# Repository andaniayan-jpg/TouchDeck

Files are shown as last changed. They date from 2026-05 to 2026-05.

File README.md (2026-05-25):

# TouchDeck

A macropad with touch sensor
TouchDeck product

Touchdeck is a macropad with touch sensitive display, it has no keys. 

## Table of Contents

WHAT IS TOUCHDECK
WHAT MAKES IT UNIQUE
FEATURES
HOW TO USE IT
BILL OF MATERIALS
SCHEMATIC OVERVIEW
PCB details
3D design 
Assembly Guide
Firmware

---

## What is TouchDeck?

TouchDeck is a device made with ESP32 as the MCU, it acts a touch pad making it both a macropad and a scribble pad. It has 2 modes.

**1.  Macropad Mode**
The screen acts like a touchpad, which digital keys visible on the screen, it enables the device to act as a Touch Screen MacroPad.

**2. Scribble Pad Mode**
When switched to Scribble pad mode, it shows a plain white canvas that can be used to take notes, doodle and etc. NOTHING IS SAVED PERMANENTLY, ONCE EXITING THIS MODE, REMOVES ALL THE WORK. 
---

## What Makes It Unique

It is unique because it doesnt use any buttons or keys like ordinary macropad, it has touch screen. It is unique because it acts as both macropad and scribble pad.
It has a customised PCB, LED, buzzer and  etc.
---

## Main Features

- ESP32-S3 based custom PCB
- 3.5 inch SPI TFT touchscreen display
- XPT2046 touch controller
- USB-C power and data
- On-screen macro buttons
- Temporary scribble/doodle mode
- Back and clear controls
- USB HID keyboard shortcut output
- WS2812B RGB status LED
- Buzzer feedback

PCB top view
PCB bottom view

---

## How to Use It

### 1. Power the Device

Connect the device with the laptop or PC. Turn on with power switch, RGB LED turns on and shows the status.

### 2. Select the mode, Macropad or scribble. 

When powered on, the screen shows two main options:

- **MacroPad Mode**
- **ScribblePad Mode**

Tap the mode you want to use.

### 3. MacroPad Mode

The touchscreen shows several shortcut buttons. When a button is touched, the ESP32-S3 sends a keyboard shortcut to the connected laptop via USB HID.

You can add, remove, increase and reduce the sizes of buttons according to your choice by changing the firmware, as it is a custom PCB!!!

### 4. ScribblePad Mode

The screen becomes a temporary drawing area. You can write with your finger or a capacitive stylus, doodle quick ideas, sketch small layouts, or scribble notes while thinking.

The drawing is **not saved** — it is purely temporary.

- **Clear** — removes the drawing from the screen
- **Back** — returns to the home screen and clears the canvas

UI overview

---

## Bill of Materials (BOM)

visit "" for BOM. 

> 
## Component connections
   for component connections, refer to the schematic image or go through the schematic source file to view exact connections. 

## Assembly Guide
   All the components used are present in the folder `cad_assembly` in STEP/STP format, for 3D model, Enclousre, and 3D parts  overview, go through that folder.

### Tools needed
-Soldering iron and flux
-Tweezers
-USB-C data cable

---
### Step 1 — Solder the Small Components

Let's start by soldering the tiny parts. First, apply some flux to the pads where the resistors and capacitors will go. Carefully position each component in place and solder them down. Since resistors and capacitors are the smallest parts, it's easier to tackle these first.

### Step 2 — Solder the USB-C Connector 

Next up is the USB-C connector. Begin by putting a little solder on the ground pads in the center of the PCB. Align the USB-C connector so all the pins match up with the pads. Tack down one corner to hold it in place, then double-check everything’s aligned before soldering the rest. Finally, solder the 5V and ground shield tabs — these will need a bit more heat to get a good connection.

### Step 3 — Solder the Voltage Regulator and ESD IC

Time to solder the voltage regulator and ESD IC. Start with the AP2112K (U2) in its SOT-23-5 package. Just make sure to pay attention to the orientation according to the silkscreen. After that, move on to the USBLC6-2SC6 (U3) in its SOT-23-6 package, keeping an eye on the pin 1 indicator.

### Step 4 — Solder the Transistor and Buzzer

For the next step, solder the transistor (Q1), which is the 2N3904 in the SOT-23 footprint. Then, insert the passive buzzer (LS1) into the through-hole, making sure the positive marking aligns with the pad label. Solder it from the bottom.

### Step 5 — Solder the WS2812B LED (U4)

Next, let’s work on the WS2812B LED, which has an integrated controller. First, apply a bit of flux to all four pads. Solder one of the corner pads first, then work on the others. Just a tip: try not to apply heat for too long on each pad.

### Step 6 — Solder the Push Buttons

Moving on, place the push buttons (SW1 for Boot and SW2 for Reset) into their through-holes. Insert them from the top and then solder their four legs from the bottom.

### Step 7 — Solder the ESP32-S3-WROOM-1 Module

This is one of the most important parts of the project. Start by applying flux on all the pads on three sides of the module footprint. Carefully position the module, ensuring the edges align with the PCB pads. Tack down two corner pads to secure it, then solder each pad using a drag-soldering method or solder wick. Make sure to check under a magnifying glass to spot any solder bridges.

Remember: **Do not solder the antenna area.** The module has a PCB antenna, so keep that section clear.

### Step 8 — Solder the Display Connector (J2)

Now, insert the 1×14 female header into J2. If you’re not using a header, you can solder wires directly instead. Solder all 14 pins from the bottom.

### Step 9 — Power-On Test (Before Display)

Before connecting the display, let's check if the power is working. Connect a USB-C cable from the board to your computer. Use a multimeter to measure the voltage between the 3.3V test point and ground. You should see a reading between **3.28–3.35V**. If it’s 0V or over 3.4V, disconnect immediately and check the solder joints on U2 and C1/C2.

### Step 10 — Attach the Display Module

Now it’s time to add the 3.5" ILI9488 display module into J2. Be careful to check the pin 1 orientation — there’s a marking on the silkscreen to help you out. If you’re doing a permanent build, you might want to use a little hot glue or double-sided foam tape to hold the display flat against the PCB.

### Step 11 — Mount Everything in the Enclosure

Finally, position the PCB in the bottom of the enclosure, making sure the mounting holes line up with the standoff posts. Insert the M2.5 × 6mm standoffs from below through the PCB holes. Then, place the enclosure top frame over the display and secure it with M2.5 × 4mm screws on both the top and bottom. 

And that’s it! At this point, you should have everything nicely assembled and ready to go.

---

---

Hardware design files are released under CERN Open Hardware Licence v2 (CERN-OHL-S).
Firmware source code is released under MIT License.
See `LICENSE` for full terms.

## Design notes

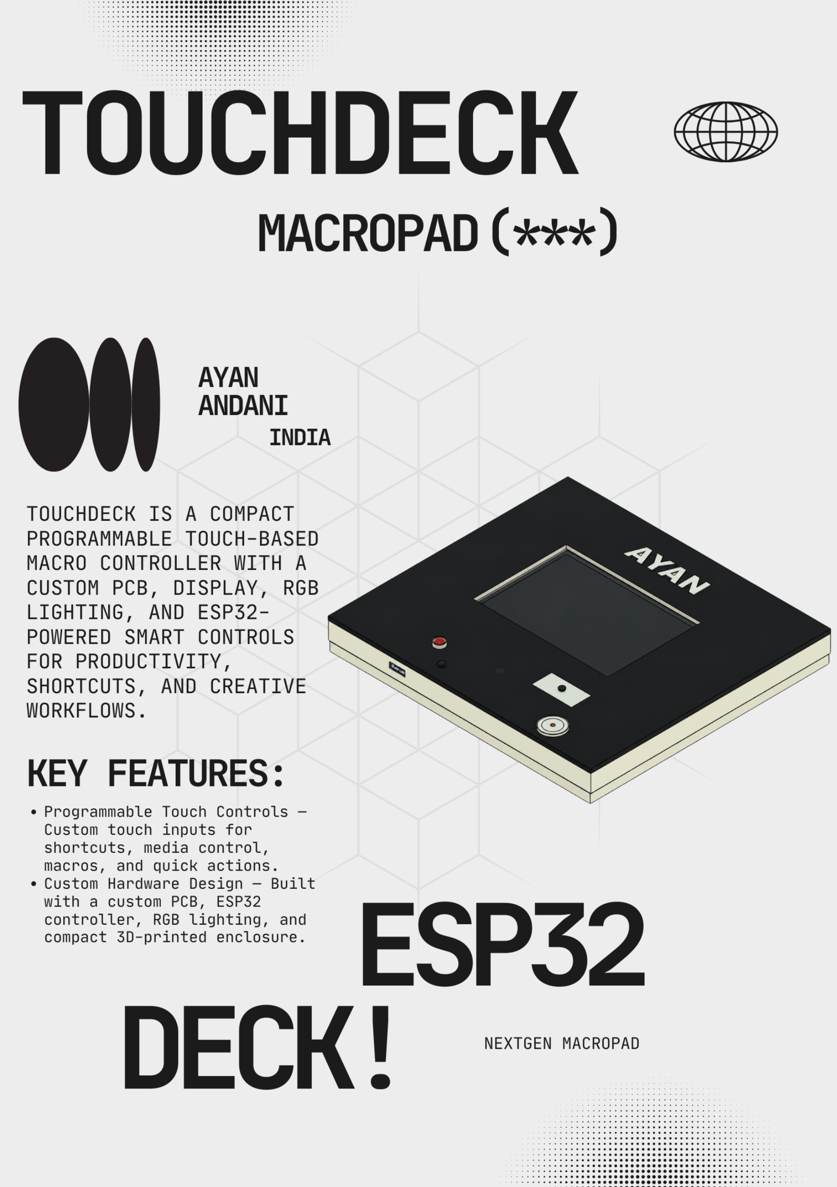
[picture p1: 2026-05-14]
Touch_Deck_zin_page.png

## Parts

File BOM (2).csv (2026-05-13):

Reference | Qty | Component | Value/Part | Footprint | Source | Link | Notes
U1 | 1 | MCU Module | ESP32-S3-WROOM-1-N8R8 | ESP32-S3-WROOM-1 | Espressif / Robu | https://www.espressif.com/en/module/esp32-s3-wroom-1-en | Main ESP32-S3 module with native USB HID capability for macropad output
Q1 | 1 | NPN Transistor | 2N3904 | TO-92_Inline | LCSC | https://www.lcsc.com/product-detail/C118538.html | Buzzer driver transistor
D1 | 1 | LED | SFH4546 5mm IR LED | LED_D5.0mm | DigiKey / ams OSRAM | https://www.digikey.in/en/products/detail/ams-osram-usa-inc/SFH-4546/2205956 | Indicator/LED footprint from PCB export; verify this is the intended LED before ordering
R6,R5 | 2 | Resistor | 10k? 0603 | R_0603_1608Metric | LCSC | https://www.lcsc.com/product-detail/C269701.html | EN/BOOT pull-up resistors
R8,R7 | 2 | Resistor | 1k? 0603 | R_0603_1608Metric | LCSC | https://www.lcsc.com/product-detail/C22548.html | Buzzer transistor base resistor and power LED/current-limit resistor
SW2,SW1 | 2 | Push Button | 6x6mm tactile push button | SW_PUSH_6mm | LCSC | https://www.lcsc.com/product-detail/C393938.html | BOOT and RESET buttons
U3 | 1 | Voltage Regulator | AP2112K-3.3 | SOT-23-5 | LCSC | https://www.lcsc.com/product-detail/C23380830.html | 3.3V LDO regulator from USB 5V
R9 | 1 | Resistor | 330 0603 | R_0603_1608Metric | LCSC | https://www.lcsc.com/product-detail/C23138.html | Series resistor for WS2812B data line
BZ1 | 1 | Buzzer | 12mm through-hole active buzzer | Buzzer_12x9.5RM7.6 | LCSC | https://www.lcsc.com/product-detail/C360615.html | Touch feedback buzzer; footprint Buzzer_12x9.5RM7.6
C1,C2 | 2 | Capacitor | 10µF 0805 ceramic capacitor | C_0805_2012Metric | LCSC | https://www.lcsc.com/product-detail/C89827.html | AP2112K regulator input/output capacitors
R1,R2 | 2 | Resistor | 5.1k? | R_0603_1608Metric | LCSC | https://www.lcsc.com/product-detail/C105580.html | USB-C CC1/CC2 pull-down resistors
U4 | 1 | USB ESD Protection | USBLC6-2SC6 | SOT-23-6 | LCSC / STMicroelectronics | https://www.lcsc.com/product-detail/C2827654.html | ESD protection for USB D+ and D- lines
D2 | 1 | Addressable RGB LED | WS2812B-B/W SMD5050-4P | LED_WS2812B_PLCC4_5.0x5.0mm_P3.2mm | LCSC | https://www.lcsc.com/product-detail/C114586.html | Mode/status RGB LED
J2 | 1 | Display Connector | 1x14 2.54mm vertical header | PinHeader_1x14_P2.54mm_Vertical | KiCad standard footprint / generic electronics supplier | https://www.lcsc.com/category/568.html | Connector footprint for external 3.5 inch SPI TFT touch display module
J1 | 1 | USB-C Receptacle | HCTL HC-TYPE-C-16P-01A | USB_C_Receptacle_HCTL_HC-TYPE-C-16P-01A | LCSC / JLCPCB | https://www.lcsc.com/product-detail/C2894897.html | USB-C power/programming/HID connection
C7 | 1 | Capacitor | 1µF 0805 ceramic capacitor | C_0805_2012Metric | LCSC | https://www.lcsc.com/product-detail/C91186.html | EN/reset stability capacitor
PCB1 | 1 | Custom PCB | TouchDeck / ScribbleDeck PCB | Gerber-manufactured PCB | JLCPCB / PCBWay | https://github.com/andaniayan-jpg/TouchDeck/blob/ea78aa653e28143bab8d7112f781ad645142ba18/pcb_source_files/TOUCHdeck%20GERBERS.zip | Main printed circuit board manufactured from Gerber files; PCB itself is included as a BOM item
DISP1 | 1 | Touch Display Module | 3.5 inch SPI TFT LCD ILI9488 + XPT2046 touch module | External module connected through J2 1x14 header | Robokits / electronics supplier | https://robokits.co.in/displays/lcd-display/spi-tft-3.5-lcd-touch-module-ili9488-driver-480x320 | Main touchscreen used for macro buttons and temporary scribble pad
CASE1 | 1 | Enclosure | Custom 3D printed TouchDeck enclosure | 3D printed part | Self-printed / 3D printing service | CAD/TouchDeck_enclosure.step | Outer case for touchscreen device
CABLE1 | 1 | USB-C Cable | USB-C data/power cable | External cable | Amazon / electronics supplier | https://www.amazon.in/Type-C-Data-Cable/s?k=Type-C+Data+Cable | Used for power, programming, and USB HID connection to laptop
MECH1 | 1 | Mounting Hardware | M2.5 hex screws | Mechanical hardware | Amazon / hardware supplier | https://www.amazon.in/binifiMux-190pcs-Socket-Assortment-Stainless/dp/B07PS8V4V3 | Used to fasten the PCB/enclosure parts

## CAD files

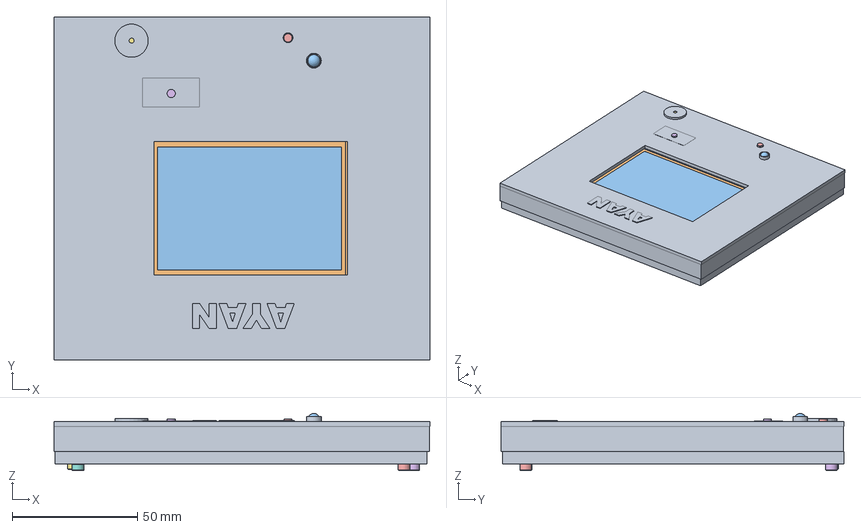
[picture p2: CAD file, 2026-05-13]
cad_assembly/fulldesign.FCStd
150.0 x 137.0 x 22.8 mm
ESP32-S3-WROOM-1
TO-92_Inline
LED_D5.0mm
R_0603_1608Metric
SW_PUSH_6mm
SOT-23-5
Buzzer_12x9.5RM7.6
C_0805_2012Metric
SOT-23-6
LED_WS2812B_PLCC4_5.0x5.0mm_P3.2mm
R_0603_1608Metric001
R_0603_1608Metric002
R_0603_1608Metric003
SW_PUSH_6mm001
R_0603_1608Metric004
C_0805_2012Metric001
R_0603_1608Metric005
USB4105GFA_USB4105GFA
R_0603_1608Metric006
C_0805_2012Metric002
Touch_PCB
3.5 LCD TFT Module - Without Glass
0603 Resistor
0603 Capacitor
3.5 LCD TFT Screen without glass
Screen
SOT23-3
0603 Resistor001
0603 Resistor002
0603 Resistor003
0603 Resistor004
SOT23-001
0603 Resistor005
0603 Capacitor001
0603 Resistor006
M2.5 Hex Screw v2
M2.5 Hex Screw v001
M2.5 Hex Screw v002
M2.5 Hex Screw v003

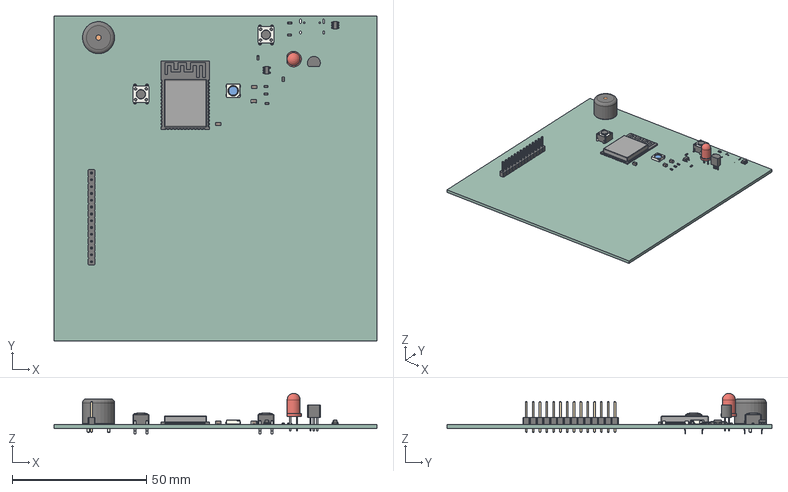
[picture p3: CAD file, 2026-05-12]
pcb_source_files/TouchdeckPCB.step
120.4 x 121.0 x 15.1 mm
ESP32-S3-WROOM-1
TO-92_Inline
LED_D5.0mm
R_0603_1608Metric x 7
SW_PUSH_6mm x 2
SOT-23-5
Buzzer_12x9.5RM7.6
C_0805_2012Metric x 3
SOT-23-6
LED_WS2812B_PLCC4_5.0x5.0mm_P3.2mm
PinHeader_1x14_P2.54mm_Vertical
Touch_PCB

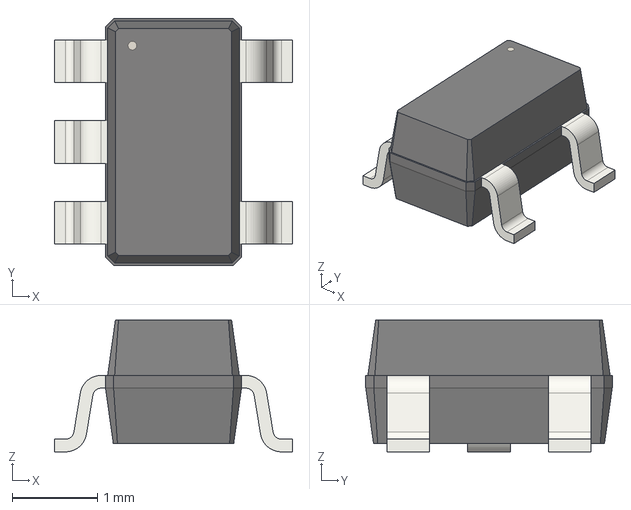
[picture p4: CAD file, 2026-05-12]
cad_assembly/SOT-23-5.step
2.80 x 2.90 x 1.55 mm

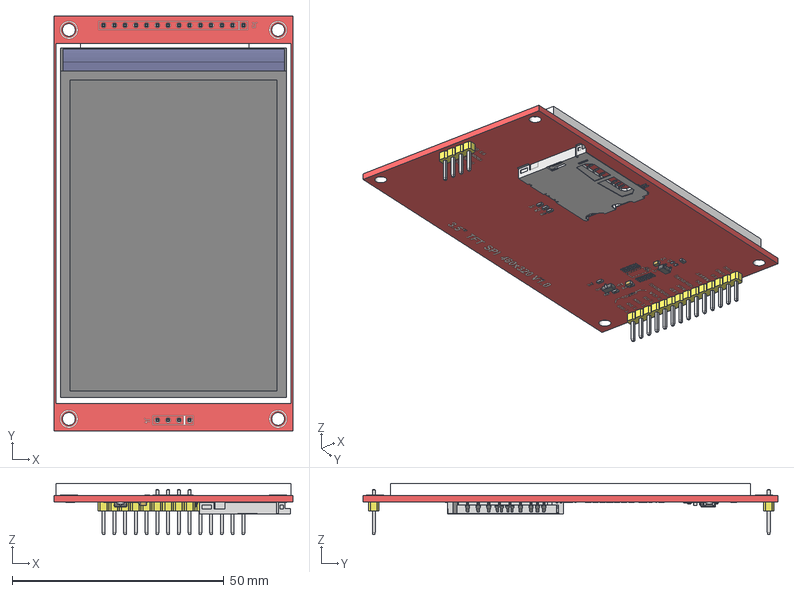
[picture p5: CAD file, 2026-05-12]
cad_assembly/3.5 TFT Module - No Glass.step
56.3 x 98.0 x 12.1 mm

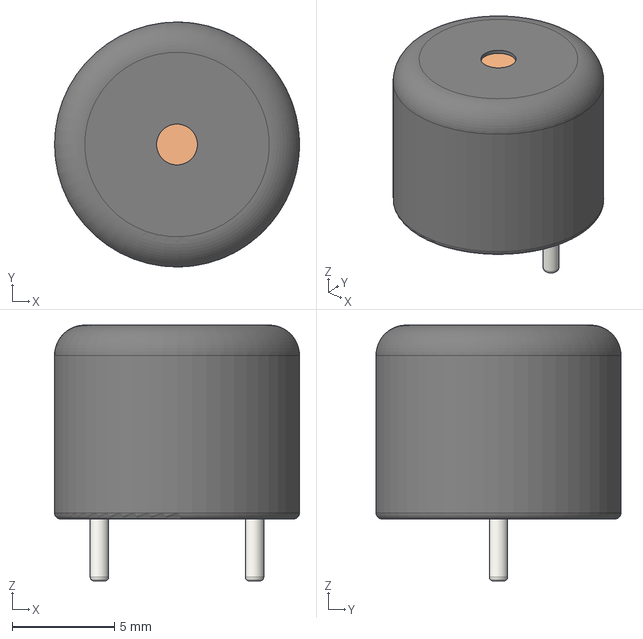
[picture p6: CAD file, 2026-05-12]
cad_assembly/Buzzer_12x9.5RM7.6.step
12.0 x 12.0 x 12.5 mm

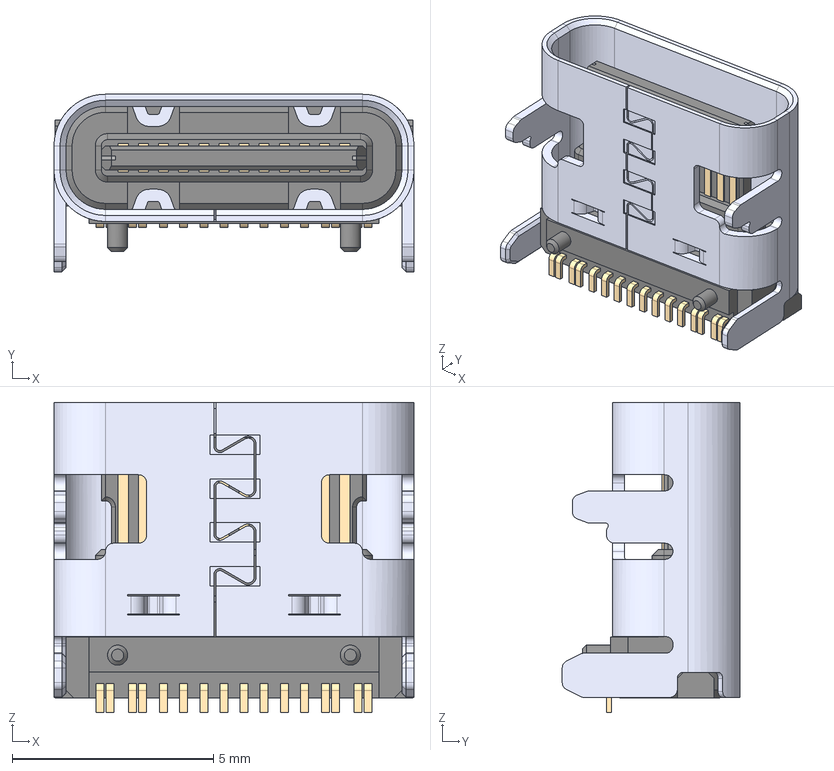
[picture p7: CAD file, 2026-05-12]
cad_assembly/USB4105GFA--3DModel-STEP-510211.step
8.94 x 4.41 x 7.71 mm

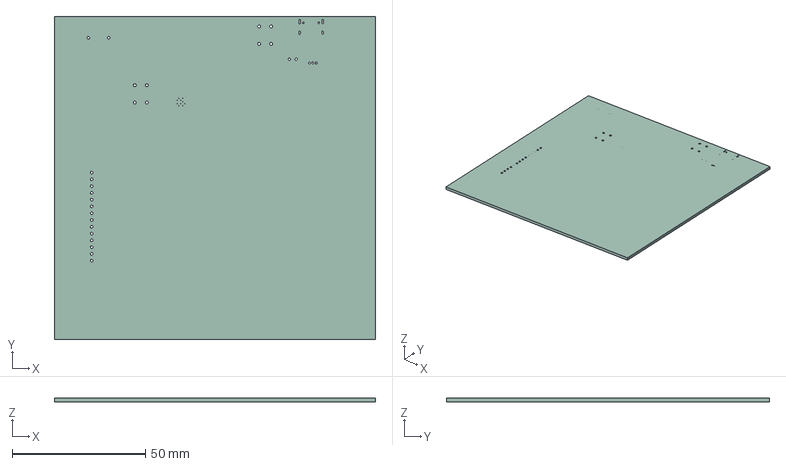
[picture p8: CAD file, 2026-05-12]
cad_assembly/Touch_PCB.step
120.4 x 121.0 x 1.51 mm

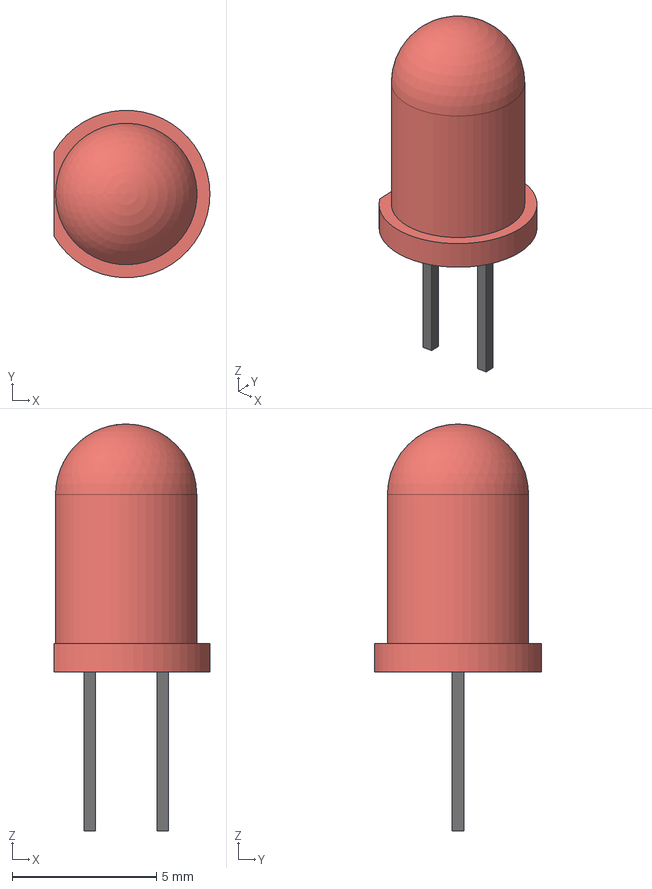
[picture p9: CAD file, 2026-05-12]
cad_assembly/LED_D5.0mm.step
5.40 x 5.79 x 14.1 mm

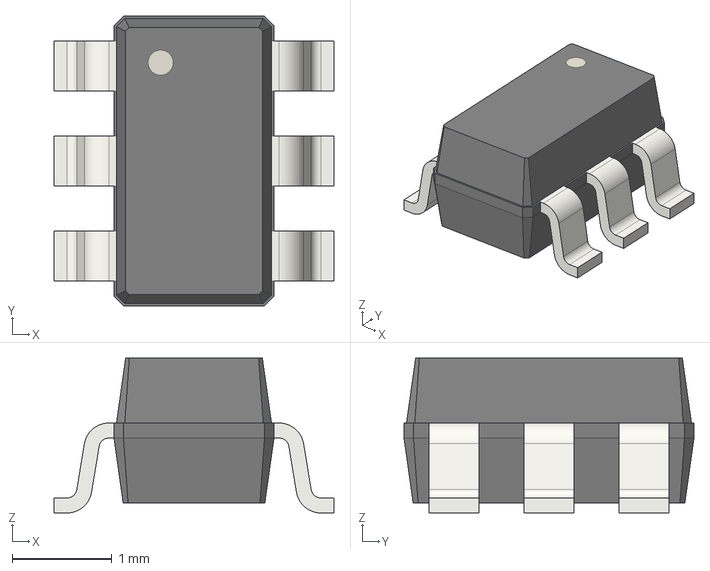
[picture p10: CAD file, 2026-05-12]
cad_assembly/SOT-23-6.step
2.80 x 2.90 x 1.55 mm

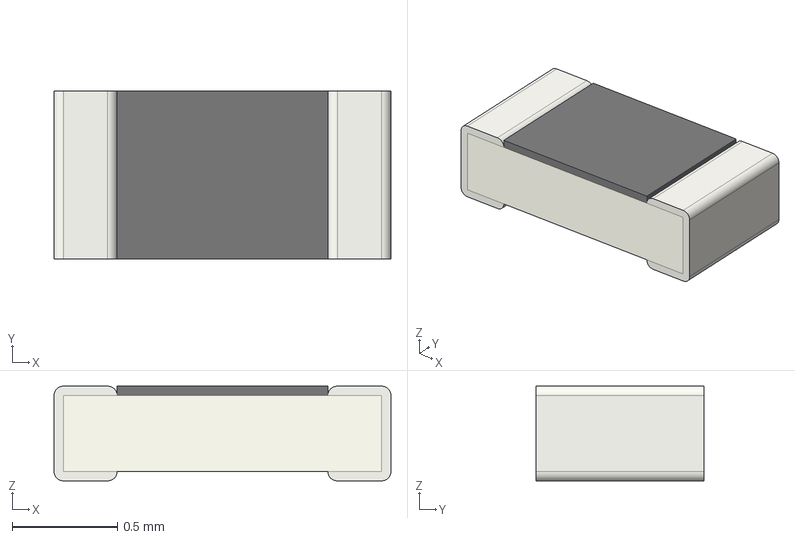
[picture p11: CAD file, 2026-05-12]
cad_assembly/R_0603_1608Metric.step
1.60 x 0.8 x 0.45 mm

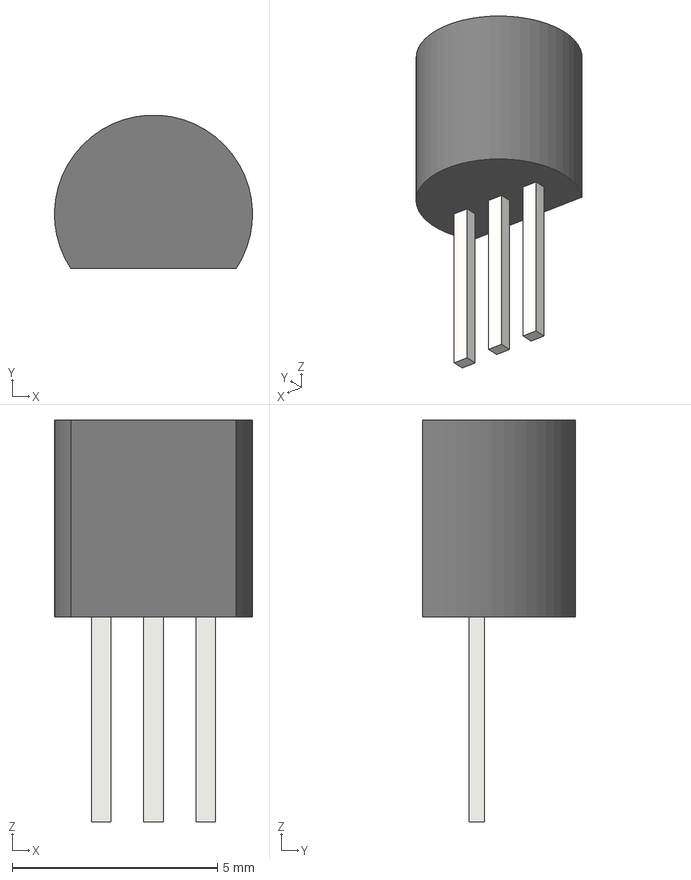
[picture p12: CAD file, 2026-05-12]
cad_assembly/TO-92_Inline.step
4.83 x 3.74 x 9.80 mm

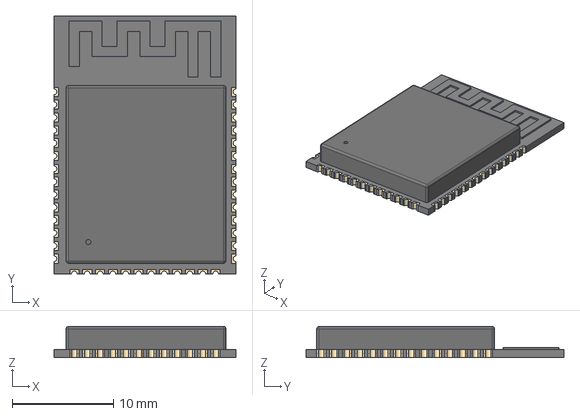
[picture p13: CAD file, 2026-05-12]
cad_assembly/ESP32-S3-WROOM-1.step
18.0 x 25.5 x 3.10 mm

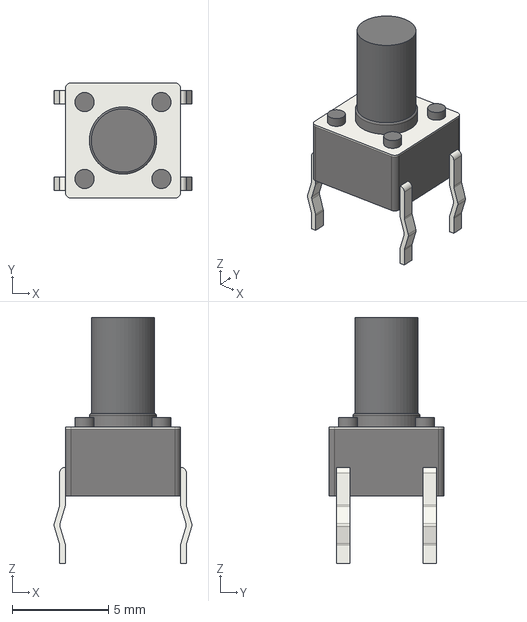
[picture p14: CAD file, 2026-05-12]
cad_assembly/SW_PUSH_6mm.step
7.17 x 6.00 x 12.8 mm

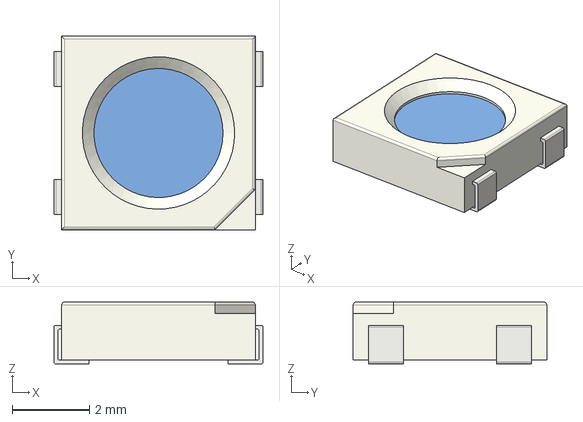
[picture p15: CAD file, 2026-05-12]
cad_assembly/LED_WS2812B_PLCC4_5.0x5.0mm_P3.2mm.step
5.40 x 5.00 x 1.60 mm

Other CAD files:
cad_assembly/FulldesignTouchDesk.step
cad_assembly/M2.5 Hex Screw v2.step

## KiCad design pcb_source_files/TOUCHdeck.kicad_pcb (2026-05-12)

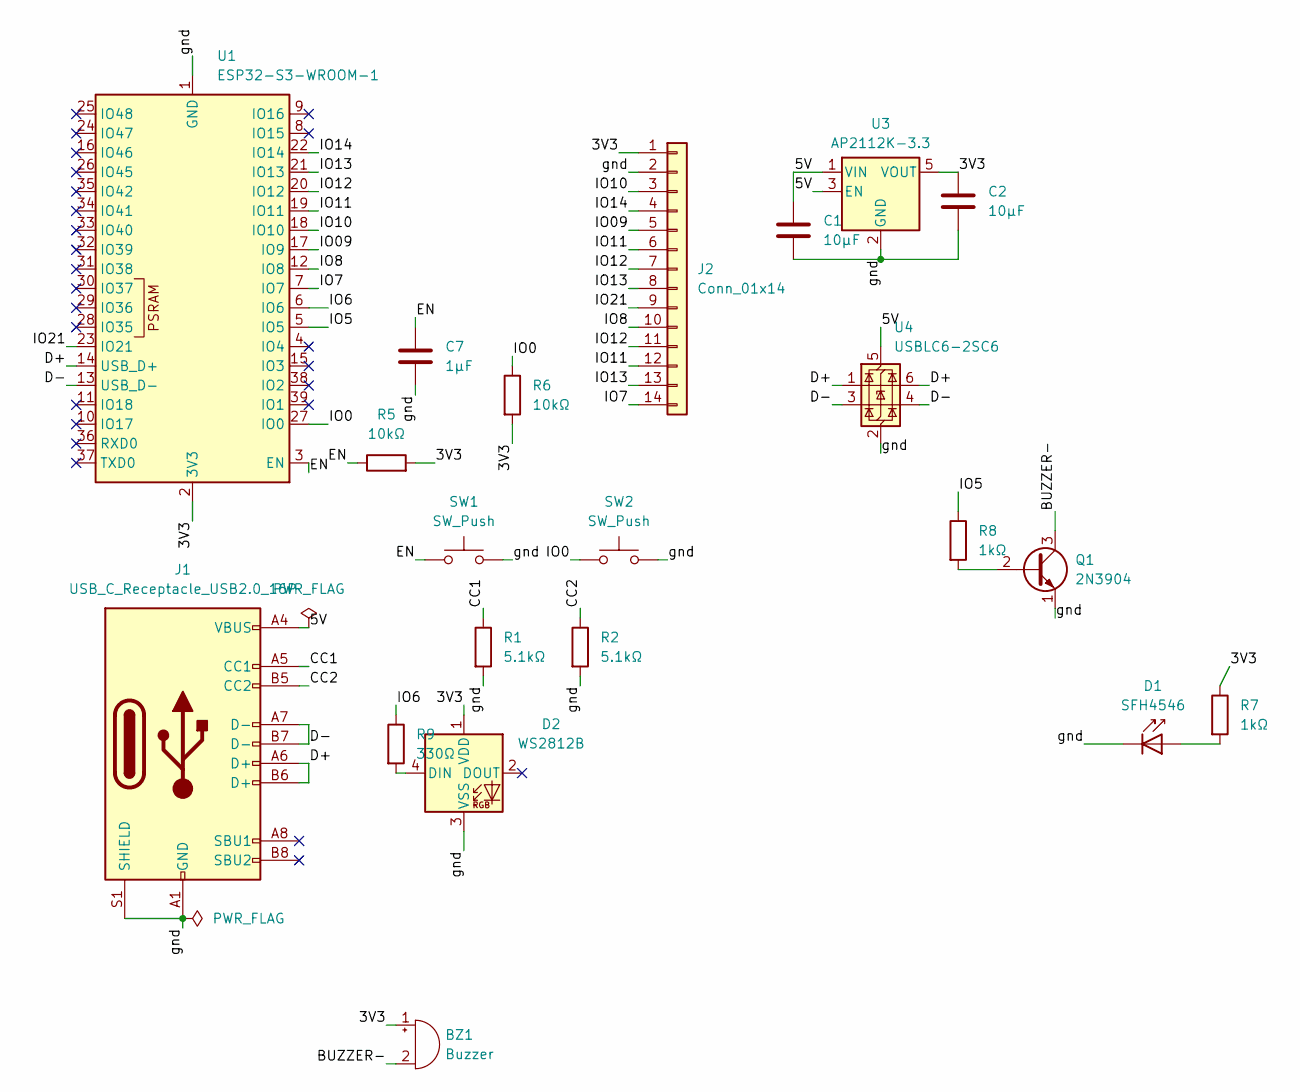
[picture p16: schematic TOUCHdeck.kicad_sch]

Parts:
BZ1: Buzzer; Buzzer_12x9.5RM7.6
C1, C2: 10μF; C_0805_2012Metric
C7: 1μF; C_0805_2012Metric
D1: SFH4546; LED_D5.0mm
D2: WS2812B; LED_WS2812B_PLCC4_5.0x5.0mm_P3.2mm
J1: USB_C_Receptacle_USB2.0_16P; USB_C_Receptacle_HCTL_HC-TYPE-C-16P-01A
J2: Conn_01x14; PinHeader_1x14_P2.54mm_Vertical
Q1: 2N3904; TO-92_Inline
R1, R2: 5.1kΩ; R_0603_1608Metric
R5, R6: 10kΩ; R_0603_1608Metric
R7, R8: 1kΩ; R_0603_1608Metric
R9: 330Ω; R_0603_1608Metric
SW1, SW2: SW_Push; SW_PUSH_6mm
U1: ESP32-S3-WROOM-1
U3: AP2112K-3.3; SOT-23-5
U4: USBLC6-2SC6; SOT-23-6

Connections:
/3V3: BZ1.1 (+), C2.2, D2.1 (VDD), J2.1 (VCC), R5.2, R6.2, R7.1, U1.2 (3V3), U3.5 (VOUT)
/5V: C1.1, J1.A4 (VBUS), J1.A9 (VBUS), J1.B4 (VBUS), J1.B9 (VBUS), U3.1 (VIN), U3.3 (EN), U4.5 (VBUS)
/BUZZER-: BZ1.2 (-), Q1.3 (C)
/CC1: J1.A5 (CC1), R1.1
/CC2: J1.B5 (CC2), R2.1
/D+: J1.A6 (D+), J1.B6 (D+), U1.14 (USB_D+), U4.1 (I/O1), U4.6 (I/O1)
/D-: J1.A7 (D-), J1.B7 (D-), U1.13 (USB_D-), U4.3 (I/O2), U4.4 (I/O2)
/EN: C7.1, R5.1, SW1.1, U1.3 (EN)
/IO0: R6.1, SW2.1, U1.27 (IO0)
/IO5: R8.1, U1.5 (IO5)
/IO6: R9.1, U1.6 (IO6)
/IO7: J2.14 (TOUCH_IRQ), U1.7 (IO7)
/IO8: J2.10 (TOUCH_CS), U1.12 (IO8)
/IO09: J2.5 (LCD_DC), U1.17 (IO9)
/IO10: J2.3 (LCD_CS), U1.18 (IO10)
/IO11: J2.6 (LCD_MOSI), J2.12 (TOUCH_DIN), U1.19 (IO11)
/IO12: J2.7 (LCD_SCK), J2.11 (TOUCH_CLK), U1.20 (IO12)
/IO13: J2.8 (LCK_MISO), J2.13 (TOUCH_DO), U1.21 (IO13)
/IO14: J2.4 (LCD_RST), U1.22 (IO14)
/IO21: J2.9 (LCD_BL), U1.23 (IO21)
/gnd: C1.2, C2.1, C7.2, D1.1 (K), D2.3 (VSS), J1.A1 (GND), J1.A12 (GND), J1.B1 (GND), J1.B12 (GND), J1.S1 (SHIELD), J2.2 (GND), Q1.1 (E), R1.2, R2.2, SW1.2, SW2.2, U1.1 (GND), U1.40 (GND), U1.41 (GND), U3.2 (GND), U4.2 (GND)
unnamed: D1.2 (A), R7.2
unnamed: D2.4 (DIN), R9.2
unnamed: Q1.2 (B), R8.2

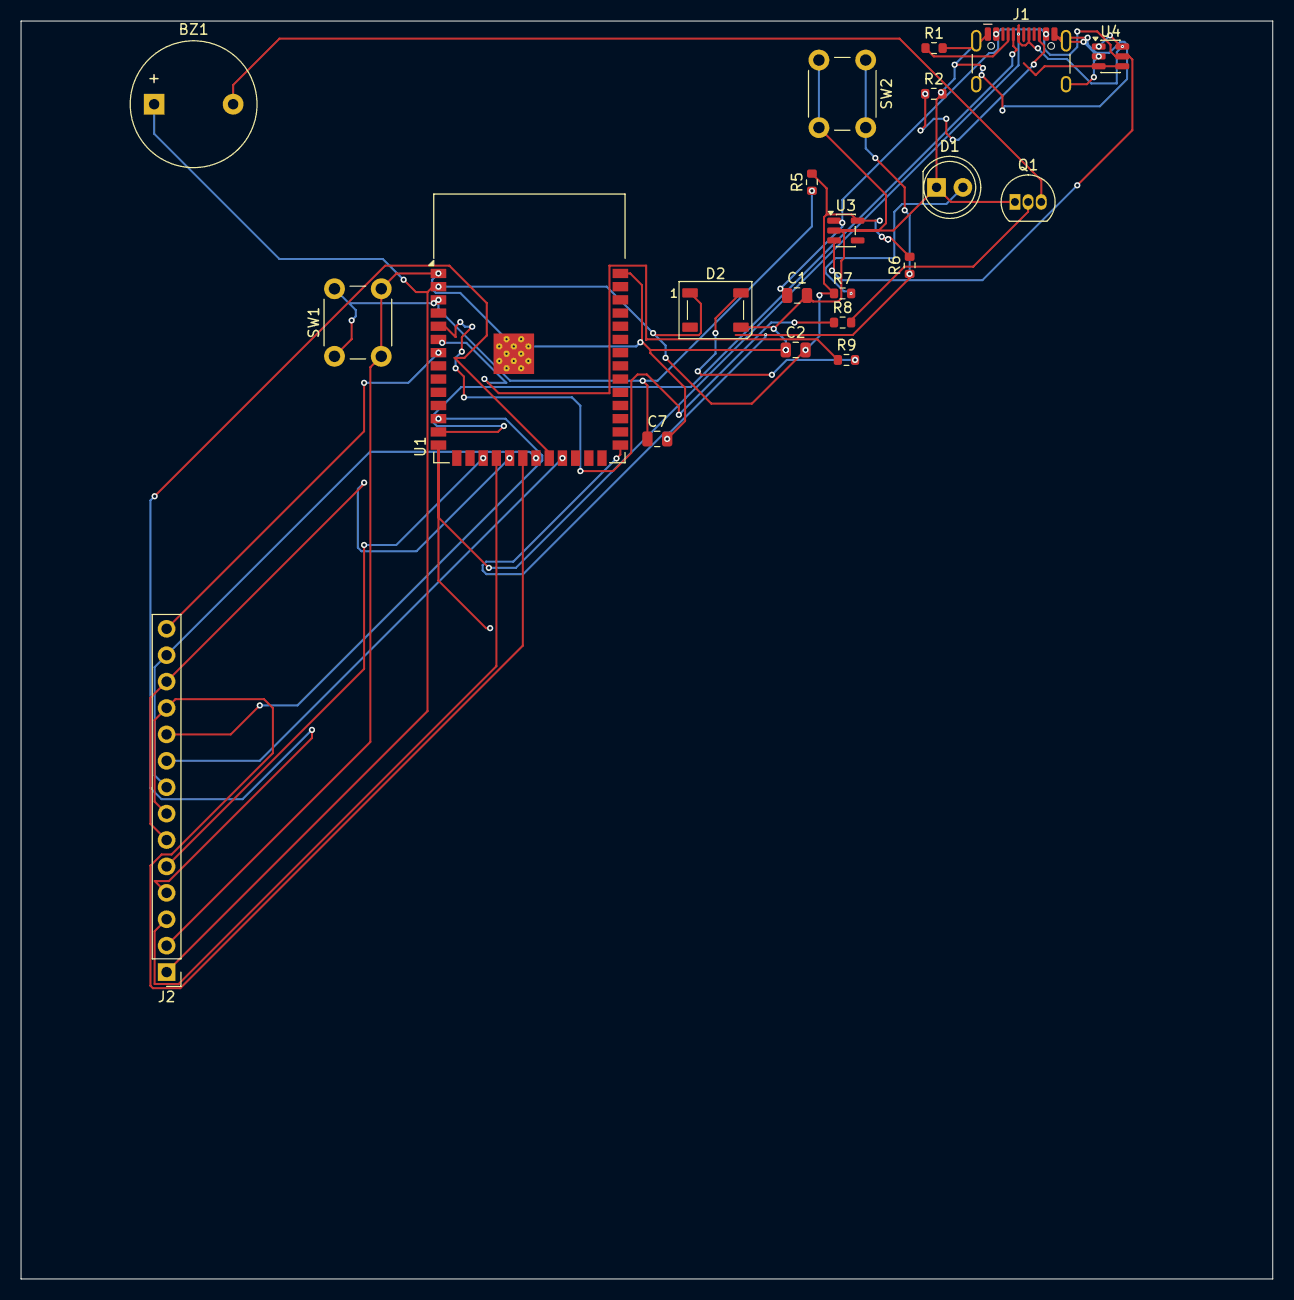
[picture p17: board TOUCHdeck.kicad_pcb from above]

Board: 2 copper layers, 120.4 x 121.0 mm, 21 parts (0 on the bottom side), 24 nets.

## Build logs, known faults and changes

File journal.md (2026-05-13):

# TouchDeck — Journal Export

- Exported at: 2026-05-13T03:27:42Z
- Project ID: 3139
- Entries: 5

## Entry 1
- ID: 6096
- Author: andaniayan
- Created At: 2026-05-08T15:06:23Z

### Content

I made the schematic for the project, it was really hard to get the touch display, i tried so many options, i even tried to make a custom symbol in kicad, but it wasnt credible, so i researched more, and finalised the** XPT2046QF**, I used a connector for that, then i added other components like voltage regulators and LEDs. 



### Recording Links

- https://lookout.hackclub.com/api/media/c42ff9a5-2a69-49ef-b493-26d76f10a56c/video.mp4
- https://lookout.hackclub.com/api/media/0fde63fd-303c-49bf-ad16-2c01ca64ac86/video.mp4

## Entry 2
- ID: 6268
- Author: andaniayan
- Created At: 2026-05-09T14:15:25Z

### Content

I completed the schematic by connecting all the elements, and assigning the footprints to all of them. 



### Recording Links

- https://lookout.hackclub.com/api/media/54ccfbc1-d232-4ffd-a457-ffbec5ed4997/video.mp4

## Entry 3
- ID: 6269
- Author: andaniayan
- Created At: 2026-05-09T14:18:06Z

### Content

I completed making the PCB for the project, I wasnt sure about the size of the display i am using, so i made a separate sketch for that, to get the reference while making the actual 3d model. I routed all the regions. 



### Recording Links

- https://lookout.hackclub.com/api/media/d4a8964c-1512-4481-bf36-c1ab6e12d81b/video.mp4

## Entry 4
- ID: 6664
- Author: andaniayan
- Created At: 2026-05-11T20:44:14Z

### Content

I made more than half of the  the 3d design of the project, I was supposed to add the separate components for some parts like the Display, to get a perfect judgement of placement. 


### Recording Links

- https://lookout.hackclub.com/api/media/3a771e71-007f-4e0f-91e4-7a2fcdaf4261/video.mp4

## Entry 5
- ID: 6820
- Author: andaniayan
- Created At: 2026-05-12T18:16:49Z

### Content

I completed the 3d design in fusion 360, I made it as compact as possible and i also kept a lid with screws, so it is easy to open/close the model whenever needed. I completed my project, and i started with making the repository. 

Screenshot 2026-05-12 185242.png

### Recording Links

- https://lookout.hackclub.com/api/media/b6eef6a6-2dc9-4583-8d3a-6f9ea83d1a4a/video.mp4

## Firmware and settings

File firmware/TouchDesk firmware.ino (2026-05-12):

/*
  ScribbleDeck S3 / TouchDeck Firmware
  ---------------------------------------------------------
  Project: Touchscreen Macropad + Temporary Scribble Pad
  Board:   ESP32-S3-WROOM-1 based custom PCB
  Display: 3.5" SPI TFT LCD, ILI9488 driver + XPT2046 touch
  UI:      Macro buttons + temporary finger scribble pad
  Output:  USB HID keyboard shortcuts to laptop

  Human note:
  This firmware is intentionally written as a hackathon-ready MVP.
  It focuses on the two core features:
    1) on-screen macropad buttons
    2) temporary scribble/doodle pad that clears when Back is pressed

  Required Arduino libraries:
    - TFT_eSPI by Bodmer
    - ESP32 Arduino core with USB HID support

  IMPORTANT TFT_eSPI setup:
  In TFT_eSPI/User_Setup.h, configure your ILI9488 + XPT2046 pins
  according to your PCB wiring. Example pins used by this firmware:

    TFT_CS   GPIO10
    TFT_RST  GPIO14
    TFT_DC   GPIO9
    TFT_MOSI GPIO11
    TFT_SCLK GPIO12
    TFT_MISO GPIO13
    TOUCH_CS GPIO8
    TFT_BL   GPIO21

  USB HID notes:
  In Arduino IDE, select an ESP32-S3 board and enable native USB mode.
*/

#include <Arduino.h>
#include <TFT_eSPI.h>
#include "USB.h"
#include "USBHIDKeyboard.h"

// -------------------- Hardware pins --------------------
#define TFT_BACKLIGHT_PIN 21
#define BUZZER_PIN         5

// -------------------- USB HID keyboard --------------------
USBHIDKeyboard Keyboard;

// -------------------- Display --------------------
TFT_eSPI tft = TFT_eSPI();

static const int SCREEN_W = 480;
static const int SCREEN_H = 320;

// Touch calibration. Tune these after running a touch calibration sketch.
uint16_t calData[5] = { 300, 3600, 300, 3600, 1 };

// -------------------- UI colors --------------------
#define COL_BG        0x18E3
#define COL_PANEL     0x2945
#define COL_CARD      0x39E7
#define COL_CARD_HIT  0x5AEB
#define COL_TEXT      0xFFFF
#define COL_MUTED     0xBDF7
#define COL_ACCENT    0x04FF
#define COL_LINE      0xFFFF

// -------------------- UI state --------------------
enum ScreenMode {
  SCREEN_HOME,
  SCREEN_MACRO,
  SCREEN_SCRIBBLE
};

ScreenMode currentScreen = SCREEN_HOME;

struct Button {
  int x, y, w, h;
  const char* label;
  uint8_t action;
};

enum MacroAction {
  ACT_NONE = 0,
  ACT_COPY,
  ACT_PASTE,
  ACT_UNDO,
  ACT_REDO,
  ACT_NEW_TAB,
  ACT_CLOSE_TAB,
  ACT_REOPEN_TAB,
  ACT_ALT_TAB,
  ACT_CHATGPT_SHORTCUT,
  ACT_VSCODE_SHORTCUT,
  ACT_PROMPT_TEMPLATE,
  ACT_MUSIC_PLAY_PAUSE
};

Button homeButtons[] = {
  { 70, 105, 340, 60, "MacroPad Mode", 1 },
  { 70, 185, 340, 60, "ScribblePad Mode", 2 }
};

Button macroButtons[] = {
  { 20,  70, 135, 52, "Copy",     ACT_COPY },
  { 165, 70, 135, 52, "Paste",    ACT_PASTE },
  { 310, 70, 135, 52, "Undo",     ACT_UNDO },

  { 20,  135, 135, 52, "Redo",    ACT_REDO },
  { 165, 135, 135, 52, "New Tab", ACT_NEW_TAB },
  { 310, 135, 135, 52, "Close",   ACT_CLOSE_TAB },

  { 20,  200, 135, 52, "Reopen",  ACT_REOPEN_TAB },
  { 165, 200, 135, 52, "Alt Tab", ACT_ALT_TAB },
  { 310, 200, 135, 52, "Prompt",  ACT_PROMPT_TEMPLATE },

  { 20,  265, 135, 42, "ChatGPT", ACT_CHATGPT_SHORTCUT },
  { 165, 265, 135, 42, "VS Code", ACT_VSCODE_SHORTCUT },
  { 310, 265, 135, 42, "Music",   ACT_MUSIC_PLAY_PAUSE }
};

Button backButton = { 380, 10, 90, 38, "Back", ACT_NONE };
Button clearButton = { 270, 10, 95, 38, "Clear", ACT_NONE };

bool wasDrawing = false;
int lastX = -1;
int lastY = -1;

// -------------------- Utility functions --------------------
bool pointInButton(int x, int y, const Button& b) {
  return (x >= b.x && x <= b.x + b.w && y >= b.y && y <= b.y + b.h);
}

void beep(uint16_t duration = 25) {
  tone(BUZZER_PIN, 2400, duration);
}

void drawHeader(const char* title) {
  tft.fillRect(0, 0, SCREEN_W, 56, COL_PANEL);
  tft.setTextColor(COL_TEXT, COL_PANEL);
  tft.setTextDatum(ML_DATUM);
  tft.drawString(title, 18, 28, 4);
}

void drawButton(const Button& b, uint16_t color = COL_CARD) {
  tft.fillRoundRect(b.x, b.y, b.w, b.h, 10, color);
  tft.drawRoundRect(b.x, b.y, b.w, b.h, 10, COL_MUTED);
  tft.setTextColor(COL_TEXT, color);
  tft.setTextDatum(MC_DATUM);
  tft.drawString(b.label, b.x + b.w / 2, b.y + b.h / 2, 2);
}

void flashButton(const Button& b) {
  drawButton(b, COL_CARD_HIT);
  delay(90);
  drawButton(b, COL_CARD);
}

// -------------------- USB HID helpers --------------------
void keyCombo(uint8_t modifier, char key) {
  Keyboard.press(modifier);
  delay(10);
  Keyboard.press(key);
  delay(30);
  Keyboard.releaseAll();
}

void keyCombo2(uint8_t modifier1, uint8_t modifier2, char key) {
  Keyboard.press(modifier1);
  Keyboard.press(modifier2);
  delay(10);
  Keyboard.press(key);
  delay(30);
  Keyboard.releaseAll();
}

void sendMacro(uint8_t action) {
  beep();

  switch (action) {
    case ACT_COPY:
      keyCombo(KEY_LEFT_CTRL, 'c');
      break;

    case ACT_PASTE:
      keyCombo(KEY_LEFT_CTRL, 'v');
      break;

    case ACT_UNDO:
      keyCombo(KEY_LEFT_CTRL, 'z');
      break;

    case ACT_REDO:
      keyCombo(KEY_LEFT_CTRL, 'y');
      break;

    case ACT_NEW_TAB:
      keyCombo(KEY_LEFT_CTRL, 't');
      break;

    case ACT_CLOSE_TAB:
      keyCombo(KEY_LEFT_CTRL, 'w');
      break;

    case ACT_REOPEN_TAB:
      keyCombo2(KEY_LEFT_CTRL, KEY_LEFT_SHIFT, 't');
      break;

    case ACT_ALT_TAB:
      Keyboard.press(KEY_LEFT_ALT);
      delay(10);
      Keyboard.press(KEY_TAB);
      delay(60);
      Keyboard.releaseAll();
      break;

    case ACT_CHATGPT_SHORTCUT:
      // Map Ctrl+Alt+C on your laptop to open ChatGPT/browser.
      Keyboard.press(KEY_LEFT_CTRL);
      Keyboard.press(KEY_LEFT_ALT);
      Keyboard.press('c');
      delay(40);
      Keyboard.releaseAll();
      break;

    case ACT_VSCODE_SHORTCUT:
      // Map Ctrl+Alt+V on your laptop to open VS Code.
      Keyboard.press(KEY_LEFT_CTRL);
      Keyboard.press(KEY_LEFT_ALT);
      Keyboard.press('v');
      delay(40);
      Keyboard.releaseAll();
      break;

    case ACT_PROMPT_TEMPLATE:
      Keyboard.print("Improve this without changing the core layout. Make it cleaner, more premium, and explain only the exact changes needed.");
      break;

    case ACT_MUSIC_PLAY_PAUSE:
      // Reliable MVP method: map Ctrl+Alt+M to play/pause on laptop if needed.
      Keyboard.press(KEY_LEFT_CTRL);
      Keyboard.press(KEY_LEFT_ALT);
      Keyboard.press('m');
      delay(40);
      Keyboard.releaseAll();
      break;

    default:
      break;
  }
}

// -------------------- Screen drawing --------------------
void drawHome() {
  currentScreen = SCREEN_HOME;
  tft.fillScreen(COL_BG);
  drawHeader("ScribbleDeck S3");

  tft.setTextDatum(MC_DATUM);
  tft.setTextColor(COL_MUTED, COL_BG);
  tft.drawString("Touch macros. Quick doodles. No physical switches.", SCREEN_W / 2, 78, 2);

  for (Button& b : homeButtons) {
    drawButton(b);
  }

  tft.setTextColor(COL_MUTED, COL_BG);
  tft.drawString("Hackathon MVP v1", SCREEN_W / 2, 292, 2);
}

void drawMacroPad() {
  currentScreen = SCREEN_MACRO;
  tft.fillScreen(COL_BG);
  drawHeader("MacroPad");
  drawButton(backButton, COL_PANEL);

  for (Button& b : macroButtons) {
    drawButton(b);
  }
}

void drawScribblePad() {
  currentScreen = SCREEN_SCRIBBLE;
  tft.fillScreen(COL_BG);
  drawHeader("ScribblePad");
  drawButton(backButton, COL_PANEL);
  drawButton(clearButton, COL_PANEL);

  tft.drawRoundRect(12, 60, SCREEN_W - 24, SCREEN_H - 72, 8, COL_MUTED);
  tft.setTextDatum(MC_DATUM);
  tft.setTextColor(COL_MUTED, COL_BG);
  tft.drawString("Draw here. Back clears everything.", SCREEN_W / 2, SCREEN_H / 2, 2);

  wasDrawing = false;
  lastX = -1;
  lastY = -1;
}

void clearScribbleArea() {
  tft.fillRect(14, 62, SCREEN_W - 28, SCREEN_H - 76, COL_BG);
  tft.drawRoundRect(12, 60, SCREEN_W - 24, SCREEN_H - 72, 8, COL_MUTED);
}

// -------------------- Touch handling --------------------
bool getTouchPoint(uint16_t& x, uint16_t& y) {
  return tft.getTouch(&x, &y, 600);
}

void handleHomeTouch(uint16_t x, uint16_t y) {
  if (pointInButton(x, y, homeButtons[0])) {
    flashButton(homeButtons[0]);
    drawMacroPad();
  } else if (pointInButton(x, y, homeButtons[1])) {
    flashButton(homeButtons[1]);
    drawScribblePad();
  }
}

void handleMacroTouch(uint16_t x, uint16_t y) {
  if (pointInButton(x, y, backButton)) {
    beep();
    drawHome();
    return;
  }

  for (Button& b : macroButtons) {
    if (pointInButton(x, y, b)) {
      flashButton(b);
      sendMacro(b.action);
      return;
    }
  }
}

void handleScribbleTouch(uint16_t x, uint16_t y) {
  if (pointInButton(x, y, backButton)) {
    beep();
    drawHome();
    return;
  }

  if (pointInButton(x, y, clearButton)) {
    beep();
    clearScribbleArea();
    wasDrawing = false;
    lastX = -1;
    lastY = -1;
    return;
  }

  if (y > 62 && y < SCREEN_H - 12 && x > 14 && x < SCREEN_W - 14) {
    if (!wasDrawing) {
      wasDrawing = true;
      lastX = x;
      lastY = y;
      tft.fillCircle(x, y, 2, COL_LINE);
    } else {
      tft.drawLine(lastX, lastY, x, y, COL_LINE);
      tft.fillCircle(x, y, 2, COL_LINE);
      lastX = x;
      lastY = y;
    }
  }
}

// -------------------- Setup and loop --------------------
void setup() {
  pinMode(TFT_BACKLIGHT_PIN, OUTPUT);
  digitalWrite(TFT_BACKLIGHT_PIN, HIGH);

  pinMode(BUZZER_PIN, OUTPUT);
  digitalWrite(BUZZER_PIN, LOW);

  Serial.begin(115200);
  delay(300);

  tft.init();
  tft.setRotation(1);
  tft.setTouch(calData);
  tft.fillScreen(COL_BG);

  Keyboard.begin();
  USB.begin();

  drawHome();

  Serial.println("ScribbleDeck S3 ready.");
  Serial.println("Use touchscreen for MacroPad or ScribblePad mode.");
}

void loop() {
  uint16_t x, y;

  if (getTouchPoint(x, y)) {
    switch (currentScreen) {
      case SCREEN_HOME:
        handleHomeTouch(x, y);
        break;

      case SCREEN_MACRO:
        handleMacroTouch(x, y);
        break;

      case SCREEN_SCRIBBLE:
        handleScribbleTouch(x, y);
        break;
    }

    if (currentScreen != SCREEN_SCRIBBLE) {
      delay(160);
    } else {
      delay(8);
    }
  } else {
    wasDrawing = false;
    lastX = -1;
    lastY = -1;
    delay(8);
  }
}
